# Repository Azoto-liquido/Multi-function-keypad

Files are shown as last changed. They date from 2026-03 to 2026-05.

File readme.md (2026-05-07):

# Multi-function keypad
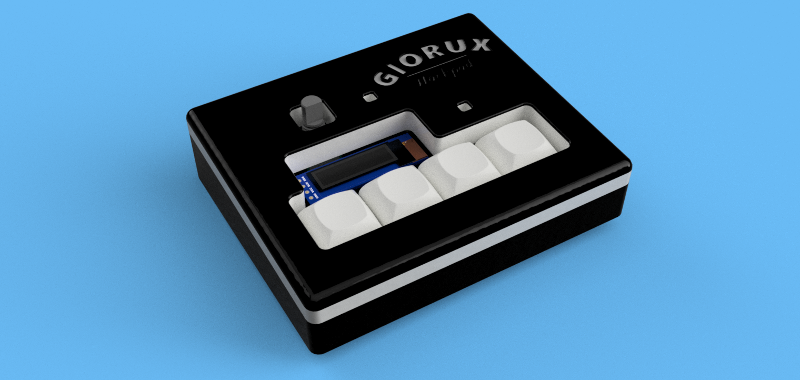
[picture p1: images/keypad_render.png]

This is a 4 switches keypad with a rotary encoder and an OLED display, it has 2 LEDs and uses QMK Firmware.

I made it to learn a bit of this topic and I think it is perfect for general porpouse, everyday shortcuts and macros in gaming. Also in the little display you could write your name or a motd.

## Bill of Materials
- 4x Cherry MX Switches
- 4x DSA Keycaps
- 4x M3x16mm SHCS Bolts
- 2x sk6812mini LEDs
- 1x 0.91" 128x32 OLED Display
- 1x EC11 Rotary Encoder
- 1x XIAO RP2040
- 1x Case (2 printed parts)

## Cad
The 2 parts are held together with 4 M3x16mm SHCS Bolts without heatset inserts (the threads are cut directly into the plastic). The case has a 4 degrees titl for better ergonomics.

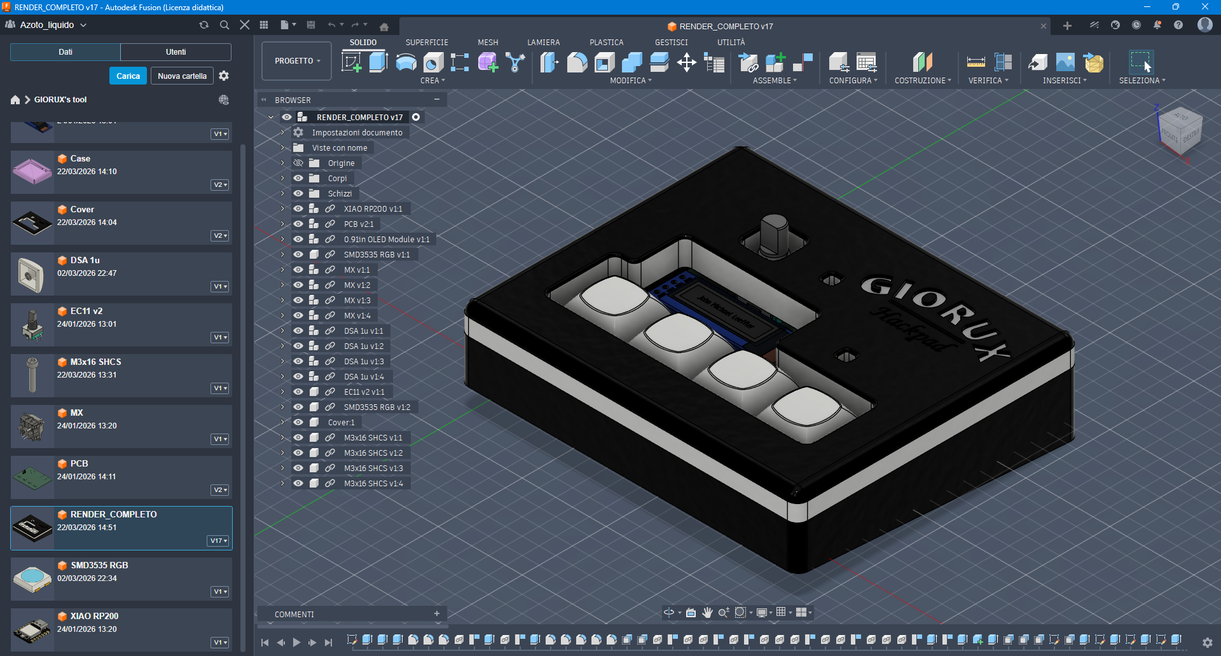
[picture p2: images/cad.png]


Made in Fusion 360.

## PCB

Schematic:
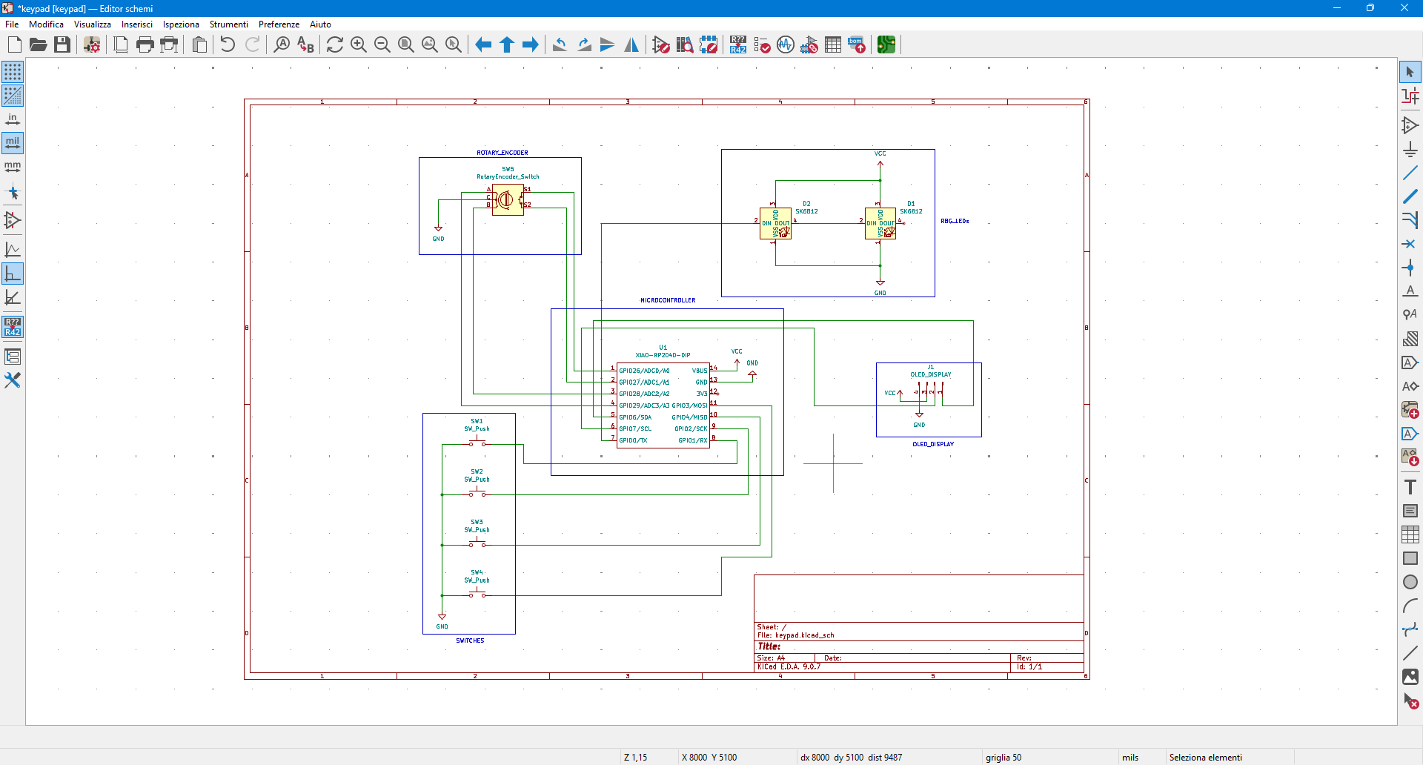
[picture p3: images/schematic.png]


PCB:
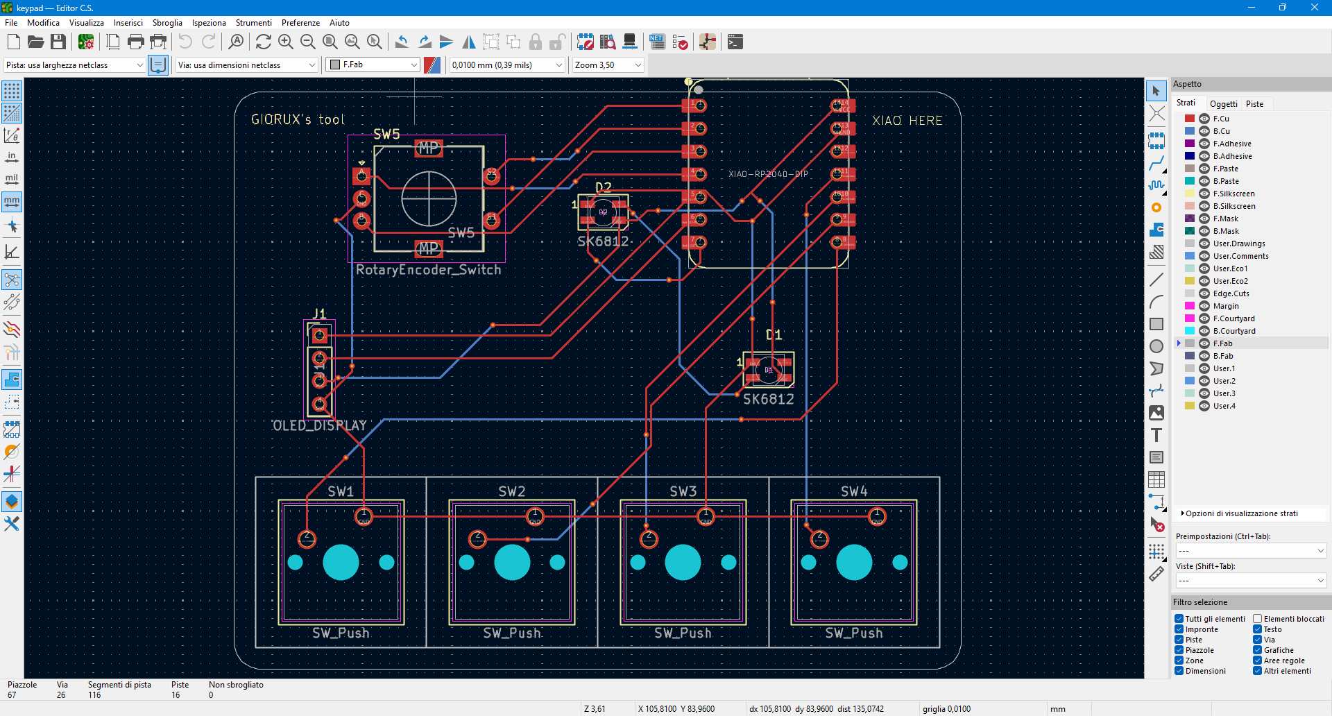
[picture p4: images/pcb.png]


## Firmware Overview
The firmware uses QMK Firmware and is fully configurable with VIA.
- The rotary encoder serves as a volume controller.
- The 4 keys can be assigned to any key with VIAA (https://caniusevia.com/).
- Holding down the 4th key will activate another layer in which the keys can be assigned to any other function.
- The OLED display can be assigned to display any text (Always in VIA).
- The 2 LEDs can display any color (This is also done in VIA).

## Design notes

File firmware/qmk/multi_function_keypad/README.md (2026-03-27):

# Multi Function Keypad – QMK Firmware

QMK firmware for a custom keyboard based on the XIAO RP2040, featuring:
- 4 Cherry MX switches
- EC11 rotary encoder
- SSD1306 OLED display 128×64
- 2 SK6812MINI RGBW LEDs

---

## Pinout

| Component | GPIO  | Notes |
|---|---|---|
| SW1 | GP1 | Cherry MX switch |
| SW2 | GP2 | Cherry MX switch |
| SW3 | GP4 | Cherry MX switch |
| SW4 | GP3 | Cherry MX switch |
| Encoder A | GP29  | EC11 channel A |
| Encoder B | GP28  | EC11 channel B |
| Encoder Switch S1 | GP26  | Push button (internal pull-up) |
| Encoder Switch S2 | GP27  | Connected to GND on PCB |
| OLED SDA | GP6 | I2C1, SSD1306 128×64 |
| OLED SCL | GP7 | I2C1 |
| LED DIN | GP0 | SK6812MINI RGBW, chain: D2 → D1 |

---

## Features

### Rotary Encoder EC11

| Action | Layer BASE | Layer FN1 |
|---|---|---|
| Turn clockwise | Volume Up | LED Brightness + |
| Turn counter-CW  | Volume Down | LED Brightness - |
| Click (GP26) | Mute toggle | Mute toggle |

### Keys – Layer BASE

| Key | Function |
|-----|---|
| SW1 | Play / Pause |
| SW2 | Stop |
| SW3 | Previous track |
| SW4 | Hold → FN1 |

### Keys – Layer FN1

| Key | Function |
|-----|---|
| SW1 | Next track |
| SW2 | Mute toggle |
| SW3 | OLED text input |
| SW4 | (held for FN1) |

### OLED Display SSD1306

The display renders 4 rows (6×8 font, 21 columns):

| Row | Content |
|-----|---|
| 0 | Fixed title "Multi Keypad" |
| 1 | Active layer number |
| 2 | Volume status: `active` / `[MUTE]` |
| 3 | Custom scrolling text |

**Scrolling behaviour:**
- Text ≤ 21 characters → centered and static
- Text > 21 characters → scrolls right to left in a continuous loop

### Setting the OLED text

**Method 1 – From the keyboard (keycode `OLED_IN`):**
1. Hold SW4 (FN1) and press SW3 → input mode activates
2. A blinking cursor appears on row 3
3. Type the desired text from the host PC
4. **Enter** = confirm | **Esc** = cancel | **Backspace** = delete

**Method 2 – From VIA:**
1. Open VIA → **OLED** tab → **Scrolling Text** field
2. Type the text and save

**Method 3 – Compile-time default in `config.h`:**
```c
#define OLED_SCROLL_TEXT "Insert text..."
```

### SK6812MINI LEDs
- 2 RGBW underglow LEDs
- Controllable from VIA in the **Lighting** tab
- On FN1 layer: encoder knob adjusts brightness
- Available effects: breathing, cycle all, cycle left-right, rainbow beacon, jellybean raindrops, pixel rain

---

## Building

```bash
# Copy the keyboard folder into your QMK installation
cp -r multi_function_keypad ~/qmk_firmware/keyboards/

# Compile
qmk compile -kb multi_function_keypad -km via

# Flash (hold BOOT on XIAO while plugging USB, then drag the .uf2 to RPI-RP2)
qmk flash -kb multi_function_keypad -km via
```

---

## File structure

```
multi_function_keypad/
├── config.h                   # Pin definitions and parameters
├── halconf.h                  # Enable I2C in ChibiOS HAL
├── mcuconf.h                  # Enable I2C1 on RP2040
├── info.json                  # Matrix, encoder, RGB matrix, layout
├── multi_function_keypad.h    # Public API header
├── multi_function_keypad.c    # OLED rendering, LED config
└── keymaps/via/
    ├── keymap.c               # Key logic, encoder, mute, OLED input
    ├── rules.mk               # Enable VIA and ENCODER_MAP
    └── via.json               # Load into VIA for key remapping
```

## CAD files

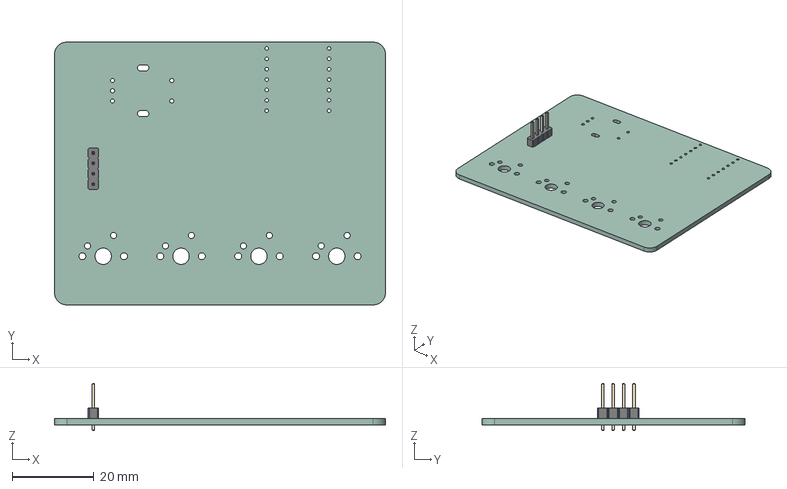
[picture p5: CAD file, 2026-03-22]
pcb/keypad/keypad.step
81.0 x 64.3 x 11.5 mm
PinHeader_1x04_P2.54mm_Vertical
Tastierino_PCB

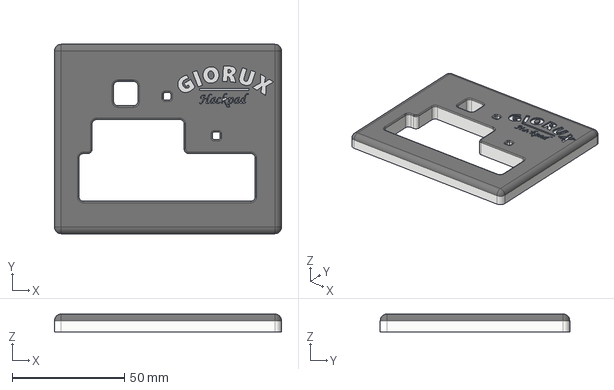
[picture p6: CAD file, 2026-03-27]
production/cad/top.step
101.0 x 84.3 x 8.00 mm

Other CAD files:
production/cad/bottom.step

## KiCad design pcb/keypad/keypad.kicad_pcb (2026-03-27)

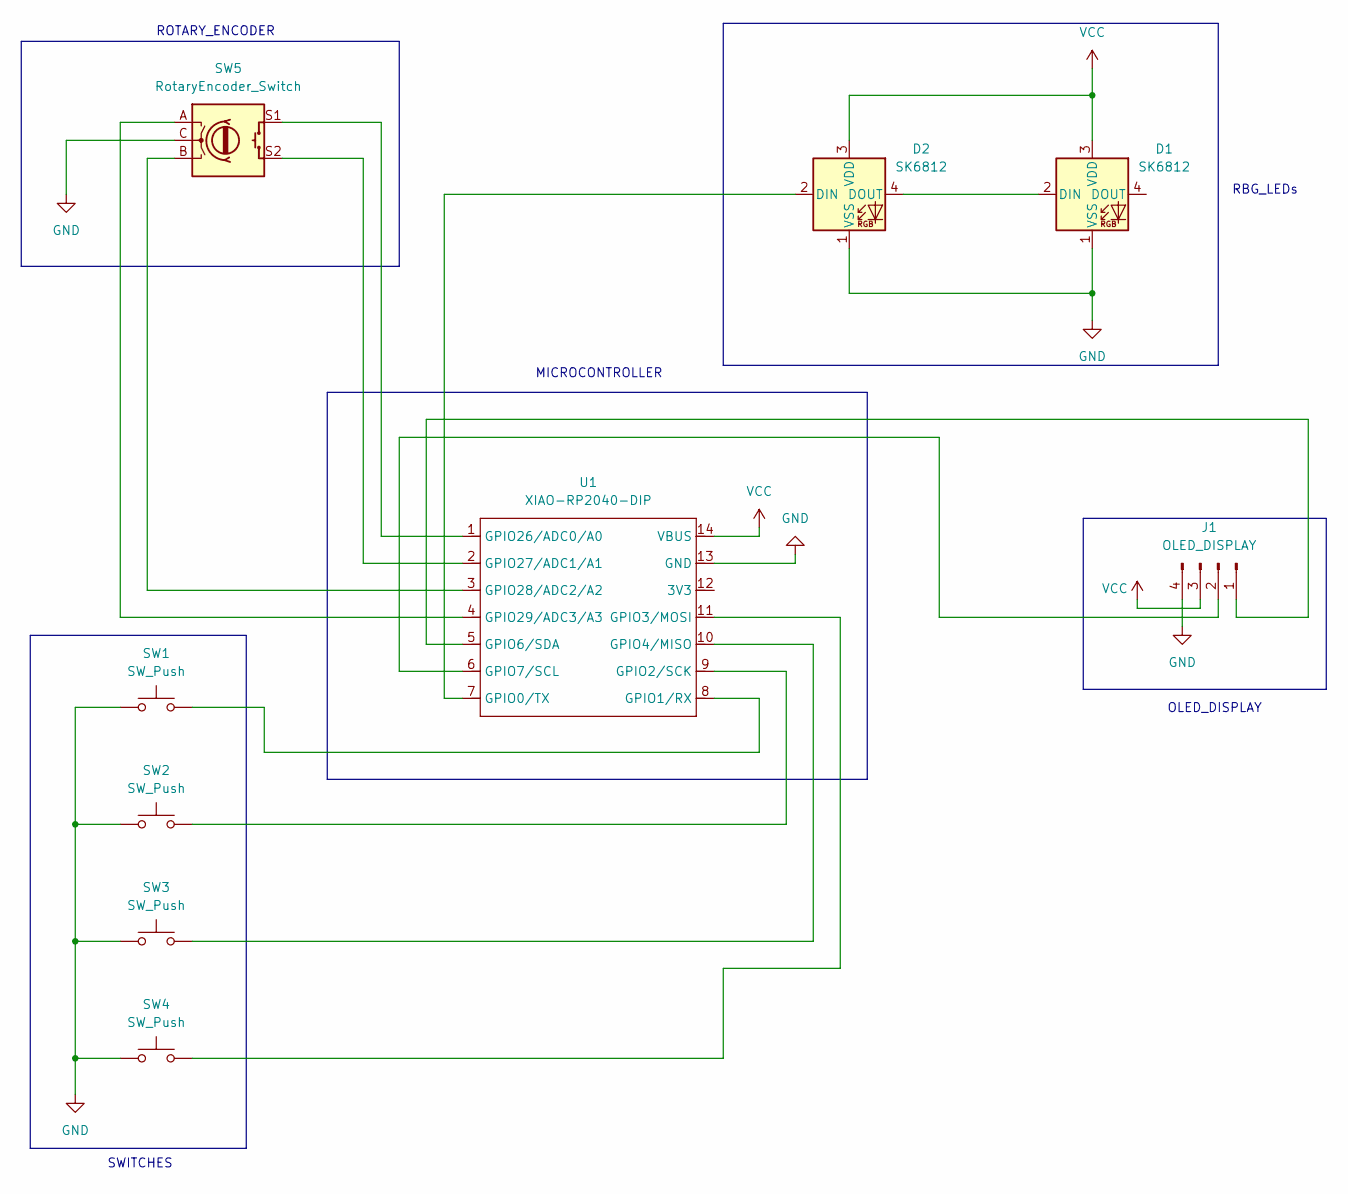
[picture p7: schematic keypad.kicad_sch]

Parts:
D1, D2: SK6812; LED_SK6812MINI_PLCC4_3.5x3.5mm_P1.75mm
J1: OLED_DISPLAY; PinHeader_1x04_P2.54mm_Vertical
SW1, SW2, SW3, SW4: SW_Push; SW_Cherry_MX_1.00u_PCB
SW5: RotaryEncoder_Switch; RotaryEncoder_Alps_EC11E-Switch_Vertical_H20mm
U1: XIAO-RP2040-DIP

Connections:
GND: D1.1 (VSS), D2.1 (VSS), J1.4, SW1.1, SW2.1, SW3.1, SW4.1, SW5.C, U1.13 (GND)
unnamed: D1.2 (DIN), D2.4 (DOUT)
unnamed: D2.2 (DIN), U1.7 (GPIO0/TX)
unnamed: J1.1, U1.5 (GPIO6/SDA)
unnamed: J1.2, U1.6 (GPIO7/SCL)
unnamed: SW1.2, U1.8 (GPIO1/RX)
unnamed: SW2.2, U1.9 (GPIO2/SCK)
unnamed: SW4.2, U1.11 (GPIO3/MOSI)
unnamed: SW3.2, U1.10 (GPIO4/MISO)
unnamed: SW5.S1, U1.1 (GPIO26/ADC0/A0)
unnamed: SW5.S2, U1.2 (GPIO27/ADC1/A1)
unnamed: SW5.B, U1.3 (GPIO28/ADC2/A2)
unnamed: SW5.A, U1.4 (GPIO29/ADC3/A3)
VCC: D1.3 (VDD), D2.3 (VDD), J1.3, U1.14 (VBUS)

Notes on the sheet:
OLED_DISPLAY
MICROCONTROLLER
RBG_LEDs
ROTARY_ENCODER
SWITCHES

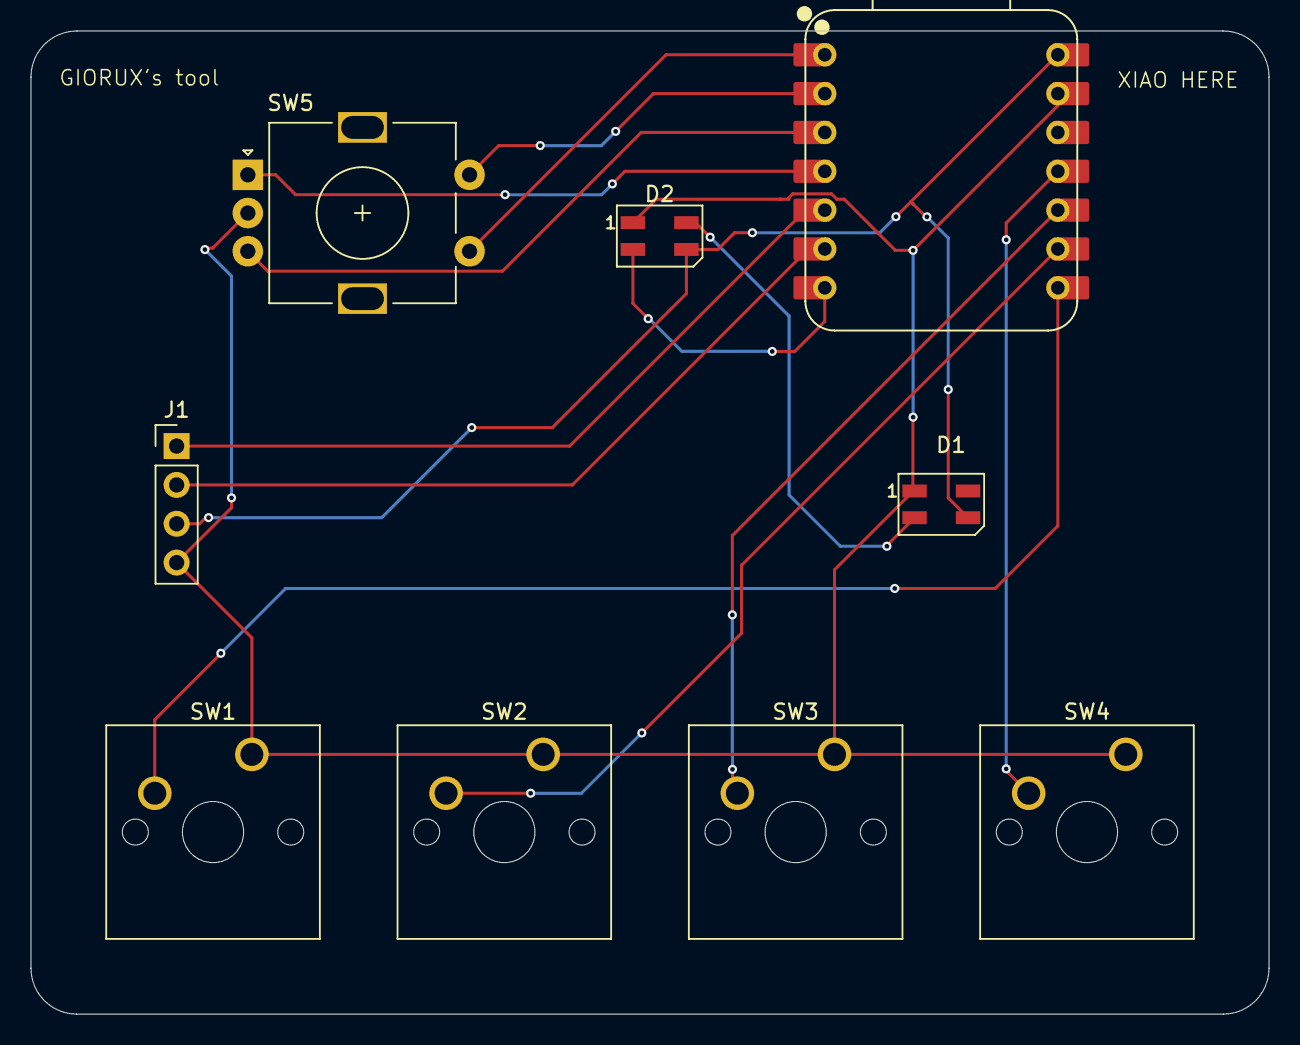
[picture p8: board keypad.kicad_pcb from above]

Board: 2 copper layers, 81.0 x 64.3 mm, 9 parts (0 on the bottom side), 14 nets.

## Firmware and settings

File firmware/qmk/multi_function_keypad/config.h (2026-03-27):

#pragma once

/* -- I2C - OLED --------------------------------------------- */
#define I2C_DRIVER   I2CD1
#define I2C1_SDA_PIN GP6
#define I2C1_SCL_PIN GP7

/* -- OLED --------------------------------------------------- */
#define OLED_DISPLAY_128X64
#define OLED_BRIGHTNESS      128
#define OLED_UPDATE_INTERVAL 33      /* ~30fps */

/* -- Encoder button ----------------------------------------- */
#define ENCODER_SWITCH_PIN GP26

/* Limit brightness to stay within 500mA USB budget */
#define RGB_MATRIX_MAXIMUM_BRIGHTNESS 200
#define RGB_MATRIX_DEFAULT_MODE       RGB_MATRIX_BREATHING
#define RGB_MATRIX_DEFAULT_HUE        170
#define RGB_MATRIX_DEFAULT_SAT        255
#define RGB_MATRIX_DEFAULT_VAL        120
#define RGB_MATRIX_DEFAULT_SPD        50

/* -- VIA ---------------------------------------------------- */
#define DYNAMIC_KEYMAP_LAYER_COUNT 4

/* -- OLED scrolling text ------------------------------------ */
#define OLED_SCROLL_TEXT  "Still got time. Use it wisely."
#define OLED_SCROLL_SPEED 6   /* frames between each one-character shift */

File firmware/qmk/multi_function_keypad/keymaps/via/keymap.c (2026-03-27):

/* ============================================================
 *  Multi Function Keypad – VIA keymap
 *
 *  Physical keys:
 *    SW1 (GP1)  SW2 (GP2)  SW3 (GP4)  SW4 (GP3)
 *
 *  Rotary encoder EC11:
 *    Turn CW   → Volume Up
 *    Turn CCW  → Volume Down
 *    Click GP26 → Mute toggle
 *
 *  Custom keycodes:
 *    CK_MUTE    – mute toggle (remappable from VIA)
 *    CK_OLED_IN – activates OLED text input mode:
 *                 type text → Enter to confirm, Esc to cancel
 * ============================================================ */

#include QMK_KEYBOARD_H
#include "multi_function_keypad.h"
#include "gpio.h"

/* ── Custom keycodes ─────────────────────────────────────── */
enum custom_keycodes {
    CK_MUTE    = QK_KB_0,
    CK_OLED_IN = QK_KB_1,
};

/* ── Layer ───────────────────────────────────────────────── */
enum layers {
    _BASE = 0,
    _FN1,
    _FN2,
    _FN3,
};

/* ── Keymap ──────────────────────────────────────────────── */
const uint16_t PROGMEM keymaps[][MATRIX_ROWS][MATRIX_COLS] = {

    /*  SW1         SW2         SW3         SW4       */
    [_BASE] = LAYOUT(
        KC_MPLY,    KC_MSTP,    KC_MPRV,    MO(_FN1)
    ),
    [_FN1] = LAYOUT(
        KC_MNXT,    CK_MUTE,    CK_OLED_IN, _______
    ),
    [_FN2] = LAYOUT(
        _______,    _______,    _______,    _______
    ),
    [_FN3] = LAYOUT(
        _______,    _______,    _______,    _______
    ),
};

/* ── Encoder map ─────────────────────────────────────────── */
#ifdef ENCODER_MAP_ENABLE
const uint16_t PROGMEM encoder_map[][NUM_ENCODERS][NUM_DIRECTIONS] = {
    [_BASE] = { ENCODER_CCW_CW(KC_VOLD, KC_VOLU) },
    [_FN1]  = { ENCODER_CCW_CW(RM_VALD, RM_VALU)  },
    [_FN2]  = { ENCODER_CCW_CW(KC_LEFT, KC_RGHT)  },
    [_FN3]  = { ENCODER_CCW_CW(KC_PGDN, KC_PGUP)  },
};
#endif

/* ── Init ────────────────────────────────────────────────── */
void keyboard_post_init_user(void) {
    gpio_set_pin_input_high(GP26);   /* encoder button S1, internal pull-up */
}

/* ── Encoder button polling on GP26 ─────────────────────── */
static bool enc_btn_prev = true;

void matrix_scan_user(void) {
    bool enc_btn = gpio_read_pin(GP26);
    if (enc_btn_prev && !enc_btn) {
        /* Falling edge = button pressed */
        is_muted = !is_muted;
        tap_code(KC_MUTE);
    }
    enc_btn_prev = enc_btn;
}

/* ── OLED text input mode ────────────────────────────────── */
static bool    oled_input_active = false;
static char    oled_input_buf[64];
static uint8_t oled_input_len    = 0;

static char keycode_to_char(uint16_t kc) {
    if (kc >= KC_A   && kc <= KC_Z)  return 'a' + (kc - KC_A);
    if (kc >= KC_1   && kc <= KC_9)  return '1' + (kc - KC_1);
    if (kc == KC_0)                  return '0';
    if (kc == KC_SPACE)              return ' ';
    if (kc == KC_MINUS)              return '-';
    if (kc == KC_DOT)                return '.';
    if (kc == KC_SLASH)              return '/';
    if (kc == KC_COMMA)              return ',';
    if (kc == KC_EQUAL)              return '=';
    if (kc == KC_EXCLAIM)            return '!';
    return 0;
}

/* ── process_record ──────────────────────────────────────── */
bool process_record_user(uint16_t keycode, keyrecord_t *record) {

    if (keycode == CK_MUTE && record->event.pressed) {
        is_muted = !is_muted;
        tap_code(KC_MUTE);
        return false;
    }

    if (keycode == CK_OLED_IN && record->event.pressed) {
        oled_input_active = true;
        oled_input_len    = 0;
        memset(oled_input_buf, 0, sizeof(oled_input_buf));
        return false;
    }

    if (oled_input_active && record->event.pressed) {
        switch (keycode) {
            case KC_ENT:
                oled_input_active = false;
                if (oled_input_len > 0)
                    oled_set_scroll_text(oled_input_buf);
                return false;

            case KC_ESC:
                oled_input_active = false;
                return false;

            case KC_BSPC:
                if (oled_input_len > 0)
                    oled_input_buf[--oled_input_len] = '\0';
                return false;

            default: {
                char c = keycode_to_char(keycode);
                if (c >= 'a' && c <= 'z' && (get_mods() & MOD_MASK_SHIFT))
                    c -= 32;
                if (c && oled_input_len < sizeof(oled_input_buf) - 1) {
                    oled_input_buf[oled_input_len++] = c;
                    oled_input_buf[oled_input_len]   = '\0';
                }
                return false;
            }
        }
    }

    return true;
}

/* ── OLED row 3 override during text input ───────────────── */
bool oled_task_user(void) {
    if (oled_input_active) {
        oled_set_cursor(0, 3);
        oled_write_P(PSTR(">"), false);
        oled_write(oled_input_buf, false);
        /* Blinking cursor */
        oled_write_char((timer_read() / 500) % 2 ? '_' : ' ', false);
        return false;   /* skip render_scroll */
    }
    return true;
}

/* ── VIA custom value: set OLED text from VIA app ────────── */
void via_custom_value_command_kb(uint8_t *data, uint8_t length) {
    if (data[0] == 0x01 && data[1] == 0x01 && length >= 3) {
        uint8_t slen = data[2];
        if (slen > 62) slen = 62;
        char tmp[64] = {0};
        memcpy(tmp, &data[3], slen);
        oled_set_scroll_text(tmp);
    }
}

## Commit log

2026-03-22 Add 3d files and pcb files
    [Case.stl, Cover.stl, keypad.kicad_pcb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]
2026-03-22 Fix error in pcb
    [keypad.kicad_pcb, keypad.kicad_sch]
2026-03-27 Fixes in folder organization
    [Case.stl, Cover.stl, bottom.step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]
2026-03-27 Major fixes in firmware and gerbers uploaded
    [keypad.kicad_pcb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]
